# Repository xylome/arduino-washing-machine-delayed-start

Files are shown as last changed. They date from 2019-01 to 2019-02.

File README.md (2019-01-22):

# Arduino washing machine delayed start
This is a little circuit to delay the start of a washing machine.
Can be used to delay anything via an optocoupler.

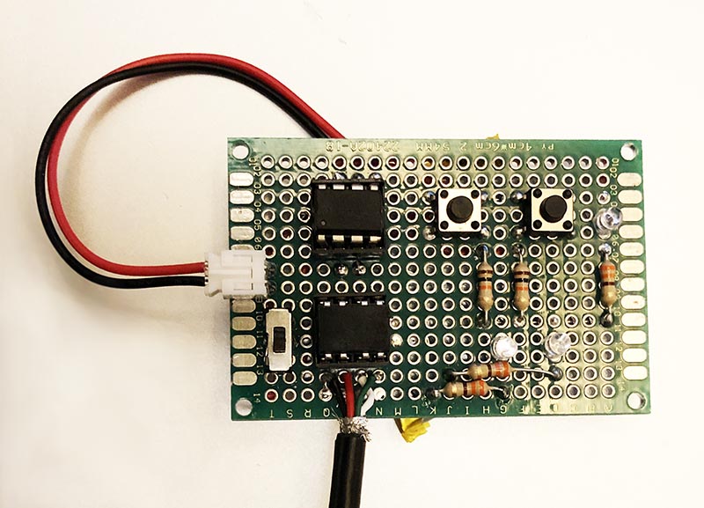
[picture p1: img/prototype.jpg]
The prototype


## How to use
When powering on the circuit, the status LED shows the default number of hours it will wait before triggering the optocoupler. Left button allows to increment that number by one hour on each pression (max 9 hours). Once set, the countdown starts when you press the button on the right.

The status LED shows the remaining hours left until the trigger.

The start of my washing machine consists in two steps :
* switch on;
* start washing;

Hence, the 2 channel optocoupler. A status LED is linked with each channel to allow troubleshooting.

When everything is done, the status LED will blink several times each 5 seconds to let you know you have to switch off the circuit.

## Parts list
* arduino :
  - development platform : arduino nano
  - target platform : attiny85
* optocoupler : ILS74 https://www.vishay.com/docs/83640/ild74.pdf
* 3 LEDS
* resistors
  - 3 * 330 ohms for the LEDS
  - 2 * 10k ohms for pullups
* 1 * lipo battery (3.7 V)

## Platform configuration
### development
  * type of card : Arduino nano
  * processor : Atmega 328P (old bootloader)
  * programmer : ArduinoISP

### target
  * type of card : ATtiny25/45/85
  * processor : attiny85
  * clock : internal 1MHz
  * programmer : Arduino as ISP

## Power consumption
This version includes sleeping mode to reduce power consumtpion : in running mode, the current intensity is about 1.3 mA. In end mode (waiting for someone to switch off the device), the intensity drops to 5 µA.
In a normal day, the consumption for my usage should be about 6,5 mAh. With a 500 mAh lipo battery, it should run 76 days in one charging cycle : wouhou ✋

## Documentation
To use arduino as ISP, I followed instructions available here : https://create.arduino.cc/projecthub/arjun/programming-attiny85-with-arduino-uno-afb829

Information about optocouplers : http://www.martyncurrey.com/arduino-with-optocouplers/

Information about sleep mode on arduino, and especially on attiny85 :
  * https://playground.arduino.cc/Learning/ArduinoSleepCode
  * https://www.re-innovation.co.uk/docs/sleep-modes-on-attiny85/

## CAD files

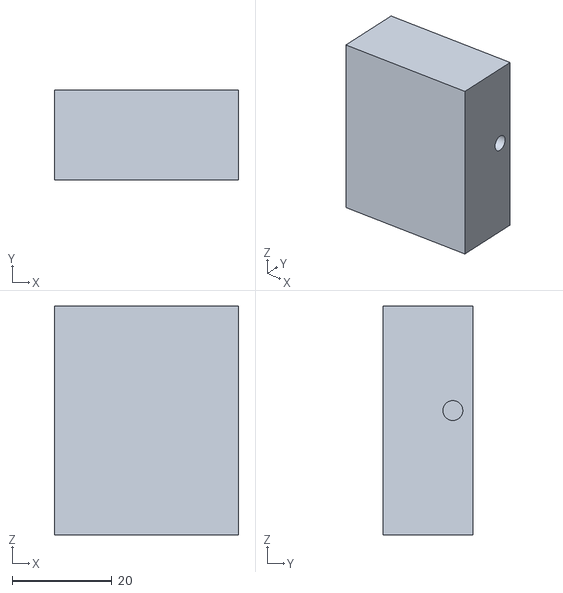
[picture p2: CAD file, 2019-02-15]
stl/main_box.stl
37.0 x 18.0 x 46.0

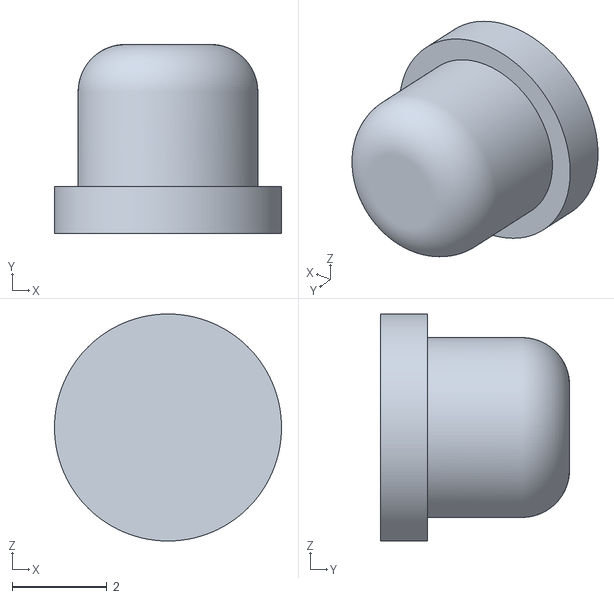
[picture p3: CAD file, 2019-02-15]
stl/button.stl
4.80 x 4.00 x 4.80

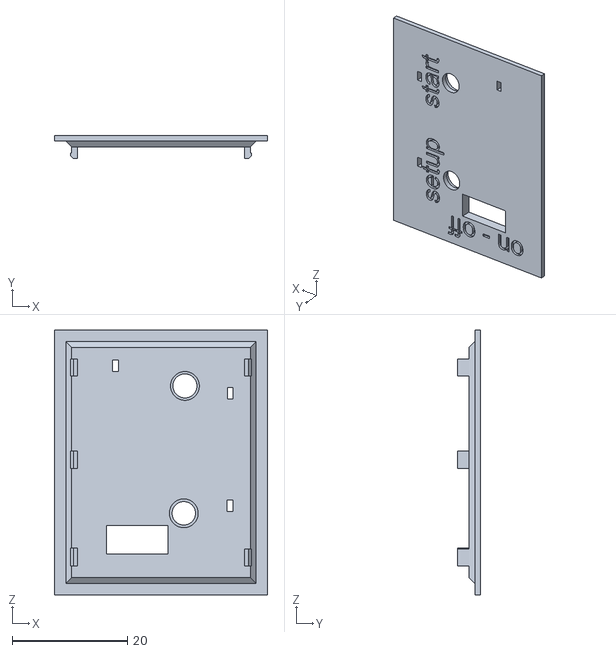
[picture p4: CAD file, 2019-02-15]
stl/top_box.stl
37.0 x 4.00 x 46.0

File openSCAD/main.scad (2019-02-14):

module prism(l, w, h){
       polyhedron(
               points=[[0,0,0], [l,0,0], [l,w,0], [0,w,0], [0,w,h], [l,w,h]],
               faces=[[0,1,2,3],[5,4,3,2],[0,4,5,1],[0,3,4],[5,2,1]]
               );

       }
       
difference() {       
translate([10, 10, 0]) color("DarkViolet") cube([35.6, 24.2, 1]);
translate([12.4,21.43,-0.1]) rotate([0, -90, 90]) prism(2, 2.6, 1.2);
translate([9.9, 21.42,-0.1]) cube([2.6, 20, 2]);
};

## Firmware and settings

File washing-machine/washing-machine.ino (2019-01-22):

/*
Copyright (C) 2019  Xavier Héroult <xavier@placard.fr.eu.org>

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
You should have received a copy of the GNU General Public License
along with this program; if not, write to the Free Software
Foundation, Inc., 51 Franklin Street, Fifth Floor, Boston, MA  02110-1301, USA.
 */
#include <avr/sleep.h>

#include <Button.h>
#if defined (__AVR_ATtiny85__)
#define BUTTON_SETUP 0
#define BUTTON_PLAY 1
#define STATUS_LED 2
#define ON_OFF 3
#define PLAY_PAUSE 4
#else
#define BUTTON_SETUP 4 
#define BUTTON_PLAY 5
#define STATUS_LED LED_BUILTIN
#define ON_OFF 2
#define PLAY_PAUSE 3
#define DEBUG ON
#endif

#define TIME_BEFORE_SETUP 200
#define TIME_DISPLAY 200
#define MAX_HOURS 9
#define DEFAULT_HOURS 5
#define SECONDS_PER_HOUR 3600

#define ON_OFF_TIME 5000
#define PAUSE_BETWEEN_ACTIONS 3000
#define PLAY_PAUSE_TIME 1000

#define END_BLINK_TIME 8
#define END_BLINK_DELAY 80

// Routines to set and clear bits (used in the sleep code)
#ifndef cbi
#define cbi(sfr, bit) (_SFR_BYTE(sfr) &= ~_BV(bit))
#endif
#ifndef sbi
#define sbi(sfr, bit) (_SFR_BYTE(sfr) |= _BV(bit))
#endif

int requested_hours;
volatile int f_timer = 0;

void system_sleep(int mode) {
  cbi(ADCSRA,ADEN);                    // switch Analog to Digitalconverter OFF
  set_sleep_mode(mode);
  sleep_enable();
  sleep_mode();                        // System actually sleeps here
  sleep_disable();                     // System continues execution here when watchdog timed out 
  sbi(ADCSRA,ADEN);                    // switch Analog to Digitalconverter ON
}

// 0=16ms, 1=32ms,2=64ms,3=128ms,4=250ms,5=500ms
// 6=1 sec,7=2 sec, 8=4 sec, 9= 8sec
void setup_watchdog(int ii) {
  byte bb;
  int ww;
  
  if (ii > 9 ) { 
    ii=9;
  }
  
  bb = ii & 7;
  if (ii > 7) {
    bb |= (1<<5);
  }
  
  bb |= (1<<WDCE);
  
  ww = bb;
 
  MCUSR &= ~(1 << WDRF);
  // start timed sequence
  WDTCR |= (1 << WDCE) | (1 << WDE);
  // set new watchdog timeout value
  WDTCR = bb;
  WDTCR |= _BV(WDIE);
}
  
// Watchdog Interrupt Service / is executed when watchdog timed out
ISR(WDT_vect) {
  f_timer = 1;  // set global flag
}

void blink(int time, int dest) {
  for (int i = 0; i < time; i++) {
    digitalWrite(dest, HIGH);
    delay(TIME_DISPLAY);
    digitalWrite(dest, LOW);
    delay(TIME_DISPLAY);
  }
}

void start_washing_machine() {
  digitalWrite(ON_OFF, HIGH);
  delay(ON_OFF_TIME);
  digitalWrite(ON_OFF, LOW);
  delay(PAUSE_BETWEEN_ACTIONS);
  digitalWrite(PLAY_PAUSE, HIGH);
  delay(PLAY_PAUSE_TIME);
  digitalWrite(PLAY_PAUSE, LOW);
}

void end_display(int dest) {
  for (int i = 0; i < END_BLINK_TIME; i++) {
    digitalWrite(dest, HIGH);
    delay(END_BLINK_DELAY);
    digitalWrite(dest, LOW);
    delay(END_BLINK_DELAY);
  }
}

void end_loop() {
  setup_watchdog(9);
  f_timer = 1;
  while(true) {
    if (f_timer == 1) {
      f_timer = 0;
      end_display(STATUS_LED);
      system_sleep(SLEEP_MODE_PWR_DOWN);
    }
  }
}

void setup() {
  Button setup_button = Button(BUTTON_SETUP, BUTTON_PULLDOWN);
  Button play_button = Button(BUTTON_PLAY, BUTTON_PULLDOWN);
  
  pinMode(STATUS_LED, OUTPUT);
  pinMode(ON_OFF, OUTPUT);
  pinMode(PLAY_PAUSE, OUTPUT);

#if defined(DEBUG)
  Serial.begin(9600);
#endif
  requested_hours = DEFAULT_HOURS;
  
  // Show us the default setting.
  delay(TIME_BEFORE_SETUP);
  blink(requested_hours, STATUS_LED);
  
  while (!play_button.isPressed()) {
    if (setup_button.isPressed()) {
      requested_hours++;
      if (requested_hours > MAX_HOURS) {
        requested_hours = 1;
      }
      blink(requested_hours, STATUS_LED);
    }
  }

  setup_watchdog(8);
}

void loop() {
  int remaining_seconds = 0;
  int remaining_hours = 0;
  int end_time = (millis() / 1000) + requested_hours * SECONDS_PER_HOUR - 1;
#if defined(DEBUG)
  Serial.println("Main loop");
  Serial.print("requestes hours: ");
  Serial.print(requested_hours);
  Serial.print("h - endTime: ");
  Serial.print(end_time);
  Serial.println("s");
#endif
  f_timer = 1;
  while (true) {
    if (f_timer == 1) {
      f_timer = 0;
      
      remaining_seconds = end_time - (millis() / 1000);
      remaining_hours = remaining_seconds / SECONDS_PER_HOUR;

#if defined(DEBUG)
      Serial.print("remaining secsonds: ");
      Serial.print(remaining_seconds);
      Serial.print("s - remaining hours: ");
      Serial.print(remaining_hours);
      Serial.print("h - end time: ");
      Serial.print(end_time);
      Serial.print("s - now: ");
      Serial.print(millis()  / 1000);
      Serial.println("s");
#endif
     
      blink(remaining_hours + 1, STATUS_LED);
      if (remaining_seconds <= 0) {
        start_washing_machine();
        end_loop();
      }
      // Cannot set above, else the internal counter is stopped.
      system_sleep(SLEEP_MODE_IDLE); 
    }
  }
}

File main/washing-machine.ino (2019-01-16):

#include <Button.h>

#define STATUS_LED 13
#define ON_OFF 2
#define PLAY_PAUSE 3

#define BUTTON_SETUP 4
#define BUTTON_PLAY 5

#define TIME_DISPLAY 200
#define MAX_HOURS 9
#define DEFAULT_HOURS 1
#define SECONDS_PER_HOUR 30

#define ON_OFF_TIME 1000
#define PAUSE_BETWEEN_ACTIONS 4000
#define PLAY_PAUSE_TIME 1000

#define MAIN_LOOP_SECONDS 2000


int requested_hours;

Button setup_button = Button(BUTTON_SETUP, BUTTON_PULLDOWN);
Button play_button = Button(BUTTON_PLAY, BUTTON_PULLDOWN);
void setup() {
  // put your setup code here, to run once:
  pinMode(STATUS_LED, OUTPUT);
  pinMode(ON_OFF, OUTPUT);
  pinMode(PLAY_PAUSE, OUTPUT);
  
  Serial.begin(9600);
  requested_hours = DEFAULT_HOURS;
  
  while (!play_button.isPressed()) {
    if (setup_button.isPressed()) {
      requested_hours++;
      if (requested_hours > MAX_HOURS) {
        requested_hours = 1;
      }
      blink(requested_hours, STATUS_LED);
    }
  }
}

void blink(int time, int dest) {
  for (int i = 0; i < time; i++) {
    digitalWrite(dest, HIGH);
    delay(TIME_DISPLAY);
    digitalWrite(dest, LOW);
    delay(TIME_DISPLAY);
  }
}

void startWashingMachine() {
  digitalWrite(ON_OFF, HIGH);
  delay(ON_OFF_TIME);
  digitalWrite(ON_OFF, LOW);
  delay(PAUSE_BETWEEN_ACTIONS);
  digitalWrite(PLAY_PAUSE, HIGH);
  delay(PLAY_PAUSE_TIME);
  digitalWrite(PLAY_PAUSE, LOW);
}

void endLoop() {
  while(true) {
    delay(10000);
  }
}

void loop() {
  int remaining_seconds = 0;
  int remaining_hours = 0;
  int endTime = requested_hours * SECONDS_PER_HOUR;
  
  while (true) {
    remaining_seconds = endTime - (millis() / 1000);
    remaining_hours = remaining_seconds / SECONDS_PER_HOUR;
    Serial.print(endTime);
    Serial.print(" - ");
    Serial.println(remaining_seconds);

    if (remaining_seconds <= 0) {
      startWashingMachine();
      endLoop();
    } else {
      blink(remaining_hours + 1, STATUS_LED);
    }
    delay(MAIN_LOOP_SECONDS);
  }
}

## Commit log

2019-01-17 conf for attiny85
    [washing-machine.fzz]
2019-01-18 add a photo of the prototype
2019-01-18 typos…
2019-01-18 Oups… Seconds…
2019-01-22 Add sleep mode to save battery life
2019-01-22 Photo with soldered cables
2019-01-22 High five ✋
2019-02-13 kicoad and gerber files
2019-02-13 kikad and gerber files
    [main-B.Cu.gbr, main-B.Mask.gbr, main-B.Paste.gbr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]
2019-02-13 remove unused fritzing
    [washing-machine.fzz]
2019-02-14 3D model of the PCB
    [main.scad]
2019-02-15 STL files of the box
    [button.stl, main_box.stl, top_box.stl]

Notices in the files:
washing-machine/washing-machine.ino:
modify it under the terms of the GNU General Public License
